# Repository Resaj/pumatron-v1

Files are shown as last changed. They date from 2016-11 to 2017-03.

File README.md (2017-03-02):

# Pumatrón V1
Pumatrón es mi primer robot de competición. Participó entre 2011 y 2013 en numerosas pruebas, como Alcabot, Cybertech, Robolid...

Se trata de un robot modular y autosoportado, capaz de adaptarse fácilmente a las pruebas de rastreadores, velocistas y laberinto.

<p align="center">
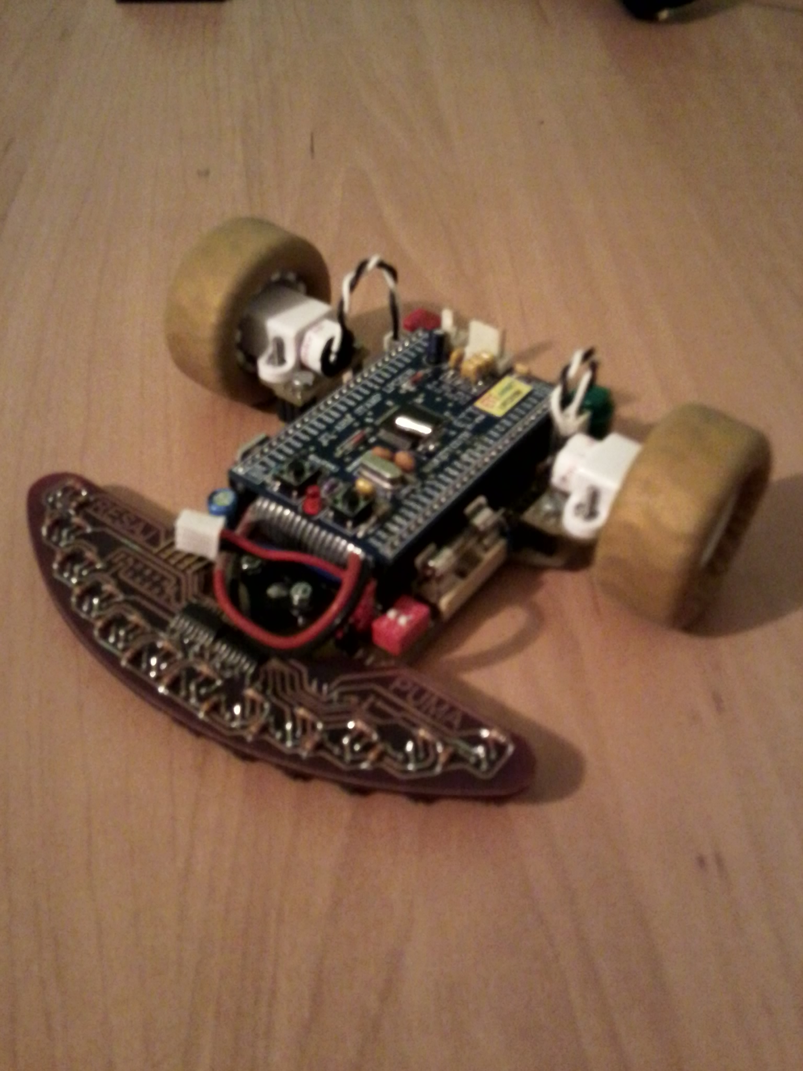
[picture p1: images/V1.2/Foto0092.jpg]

</p>

## Autor
[Rubén Espino San José](https://github.com/Resaj)

## License
<p align="center">

</p>

Todos estos productos están liberados mediante [Creative Commons Attribution-ShareAlike 4.0 International License](http://creativecommons.org/licenses/by-sa/4.0/).  
_All these products are released under [Creative Commons Attribution-ShareAlike 4.0 International License](http://creativecommons.org/licenses/by-sa/4.0/)._

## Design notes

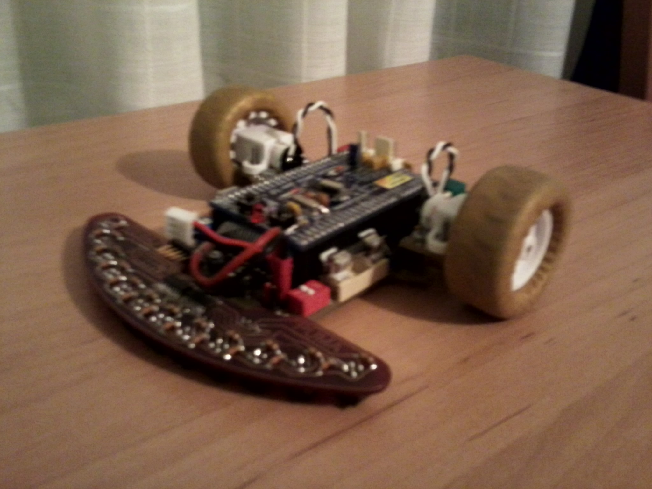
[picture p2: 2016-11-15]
images/V1.2/Foto0095.jpg

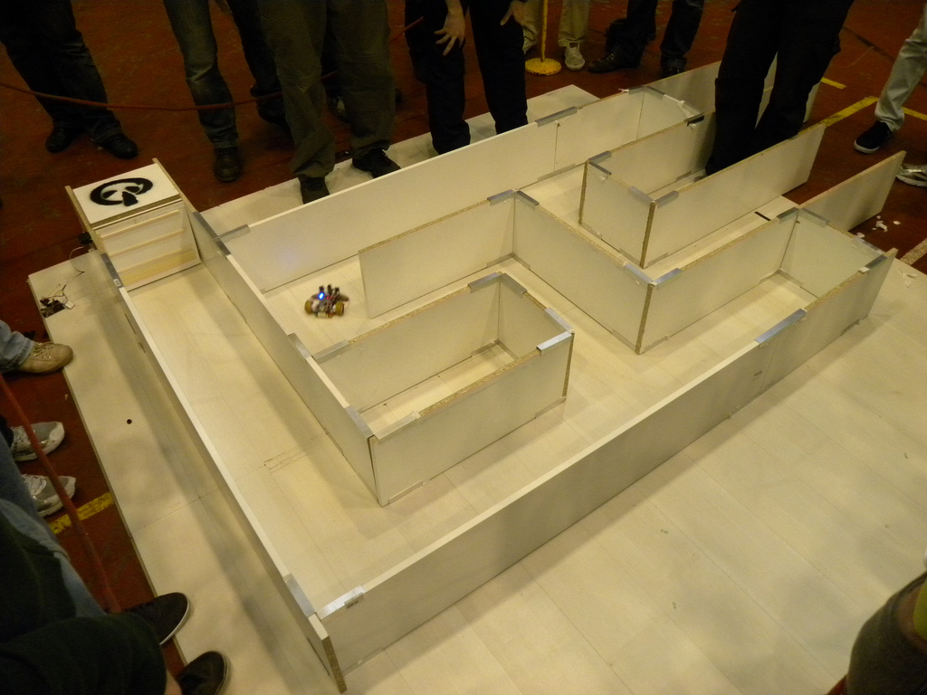
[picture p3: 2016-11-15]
images/V1.2/6978497396_52f8bebbc2_b.jpg

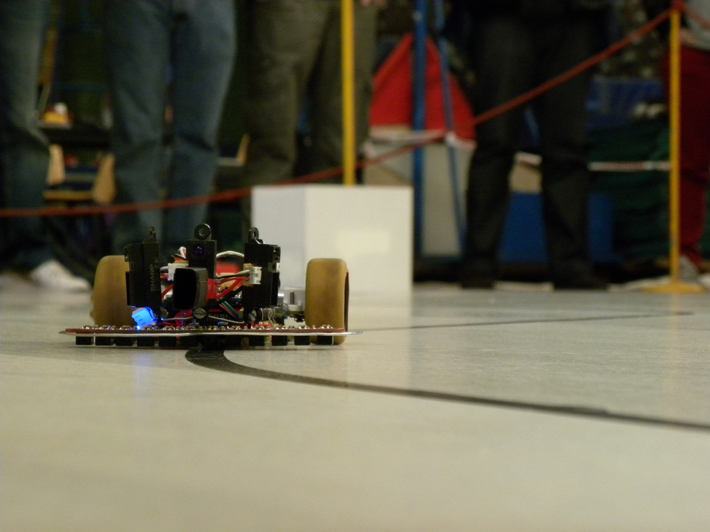
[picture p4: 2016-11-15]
images/V1.2/6978640872_f2e33e7ffb_b.jpg

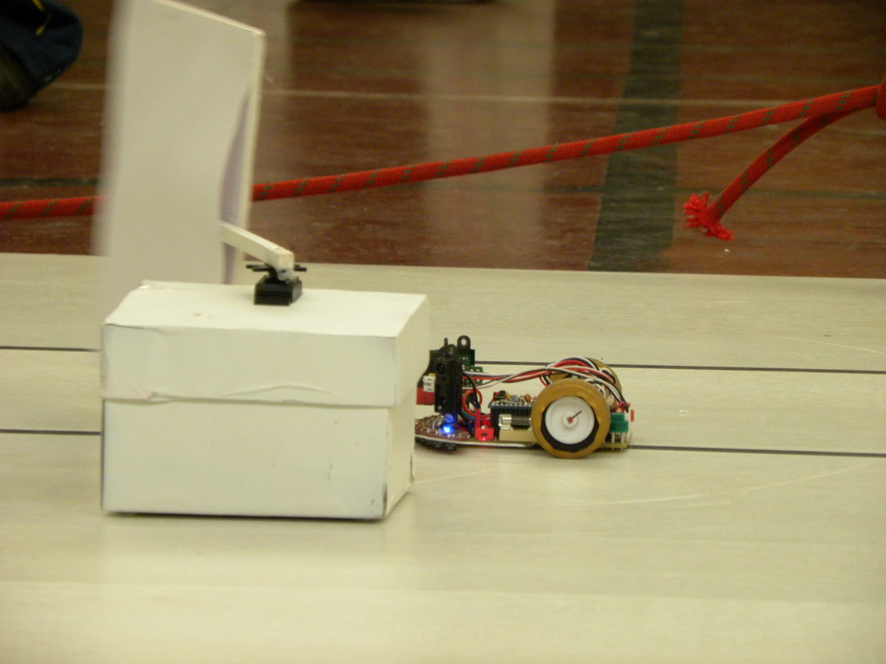
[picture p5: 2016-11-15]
images/V1.2/6978671704_61be949036_b.jpg

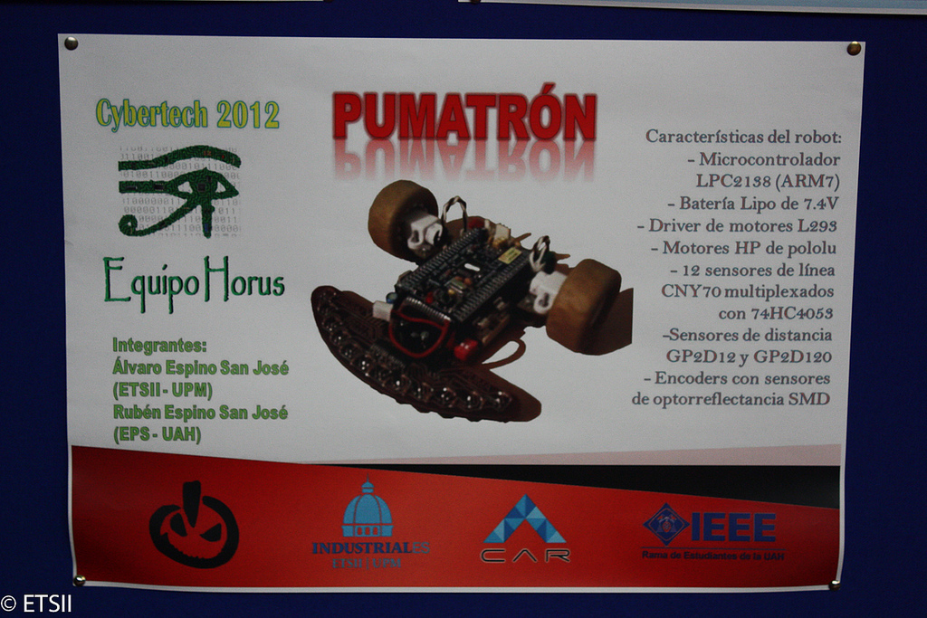
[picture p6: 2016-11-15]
images/V1.2/6982333434_18f1ba5d6d_b.jpg

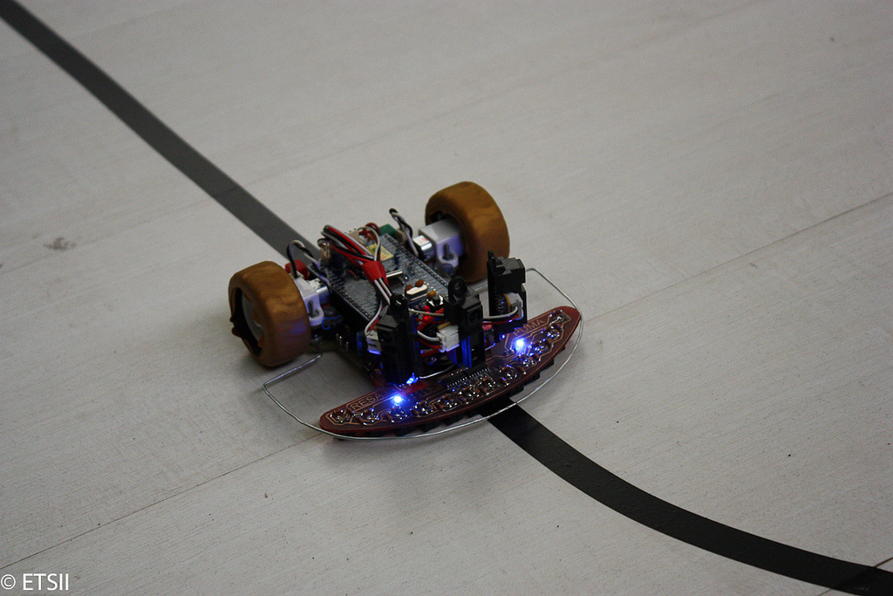
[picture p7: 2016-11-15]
images/V1.2/6982334384_aaf5ecdfa9_b.jpg

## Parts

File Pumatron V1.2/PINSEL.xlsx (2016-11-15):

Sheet: PINSEL
 | PINSEL0 | Pin Name | Function | Function | Function | Function | Reset |  | PINSEL2 | Pin Name | Function
 |  |  | when 00 | when 01 | when 10 | when 11 | Value |  |  |  | when 00
UART | 1 . 0 | P0.0 | GPIO Port 0.0 | TxD (UART0) | PWM1 | Reserved | 0 | LCD | 3 . 2 | P1.16 | GPIO Port 1.16
 | 3 . 2 | P0.1 | GPIO Port 0.1 | RxD (UART0) | PWM3 | EINT0 | 0 |  |  | P1.17 | GPIO Port 1.17
MEMORIA | 5 . 4 | P0.2 | GPIO Port 0.2 | SCL0 (I2C) | Capture 0.0 | Reserved | 0 |  |  | P1.18 | GPIO Port 1.18
PULSADOR / MEMORIA | 7 . 6 | P0.3 | GPIO Port 0.3 | SDA0 (I2C) | Match 0.0 | EINT1 | 0 |  |  | P1.19 | GPIO Port 1.19
SENSORES | 9 . 8 | P0.4 | GPIO Port 0.4 | SCK (SPI0) | Capture 0.1 | AD0.6 | 0 |  |  | P1.20 | GPIO Port 1.20
 | 11 . 10 | P0.5 | GPIO Port 0.5 | MISO (SPI0) | Match 0.1 | AD0.7 | 0 | INTERRUPTOR |  | P1.21 | GPIO Port 1.21
SENSORES DISTANCIA / WP MEMORIA | 13 . 12 | P0.6 | GPIO Port 0.6 | MOSI (SPI0) | Capture 0.2 | AD1.0 | 0 | LED |  | P1.22 | GPIO Port 1.22
PWM IZQUIERDO | 15 . 14 | P0.7 | GPIO Port 0.7 | SSEL (SPI0) | PWM2 | EINT2 | 0 | LED |  | P1.23 | GPIO Port 1.23
PWM DERECHO | 17 . 16 | P0.8 | GPIO Port 0.8 | TxD (UART1) | PWM4 | AD1.1 | 0 |  |  | P1.24 | GPIO Port 1.24
PULSADOR | 19 . 18 | P0.9 | GPIO Port 0.9 | RxD (UART1) | PWM6 | EINT3 | 0 |  |  | P1.25 | GPIO Port 1.25
ENCODER | 21 . 20 | P0.10 | GPIO Port 0.10 | RTS (UART1) | Capture 1.0 | AD1.2 | 0 |  |  | P1.26 | GPIO Port 1.26
 | 23 . 22 | P0.11 | GPIO Port 0.11 | CTS (UART1) | Capture 1.1 | SCL1 (I2C1) | 0 |  |  | P1.27 | GPIO Port 1.27
SENSORES DISTANCIA | 25 . 24 | P0.12 | GPIO Port 0.12 | DSR (UART1) | Match 1.0 | AD1.3 | 0 |  |  | P1.28 | GPIO Port 1.28
 | 27 . 26 | P0.13 | GPIO Port 0.13 | DTR (UART1) | Match 1.1 | AD1.4 | 0 |  |  | P1.29 | GPIO Port 1.29
PULSADOR LOAD | 29 . 28 | P0.14 | GPIO Port 0.14 | CD (UART1) | EINT1 | SDA1 (I2C1) | 0 | SENTIDO M.I. - |  | P1.30 | GPIO Port 1.30
SENSORES DISTANCIA | 31 . 30 | P0.15 | GPIO Port 0.15 | RI (UART1) | EINT2 | AD1.5 | 0 | SENTIDO M.I. + |  | P1.31 | GPIO Port 1.31
 | PINSEL1 | Pin Name | Function | Function | Function | Function | Reset
 |  |  | when 00 | when 01 | when 10 | when 11 | Value
TIMER | 1 . 0 | P0.16 | GPIO Port 0.16 | EINT0 | Match 0.2 | Capture 0.2 | 0
ENCODER | 3 . 2 | P0.17 | GPIO Port 0.17 | Capture 1.2 | SCK (SSP) | Match 1.2 | 0
SENSOR INFRARROJO | 5 . 4 | P0.18 | GPIO Port 0.18 | Capture 1.3 | MISO (SSP) | Match 1.3 | 0
 | 7 . 6 | P0.19 | GPIO Port 0.19 | Match 1.2 | MOSI (SSP) | Match 1.3 | 0
SENTIDO M.D. - | 9 . 8 | P0.20 | GPIO Port 0.20 | Match 1.3 | SSEL (SSP) | EINT3 | 0
PWM SERVO | 11 . 10 | P0.21 | GPIO Port 0.21 | PWM5 | AD1.6 | Capture 1.3 | 0
SENSORES DISTANCIA | 13 . 12 | P0.22 | GPIO Port 0.22 | AD1.7 | Capture 0.0 | Match 0.0 | 0
SENTIDO M.D. + | 15 . 14 | P0.23 | GPIO Port 0.23 | Reserved | Reserved | Reserved | 0
 | 17 . 16 | P0.24 | Reserved | Reserved | Reserved | Reserved | 0
MULTIPLEXOR | 19 . 18 | P0.25 | GPIO Port 0.25 | AD0.4 | Aout (DAC) | Reserved | 0
SENSORES | 21 . 20 | P0.26 | GPIO Port 0.26 | AD0.5 | Reserved | Reserved | 0
LED | 23 . 22 | P0.27 | GPIO Port 0.27 | AD0.0 | Capture 0.1 | Match 0.1 | 1
SENSORES | 25 . 24 | P0.28 | GPIO Port 0.28 | AD0.1 | Capture 0.2 | Match 0.2 | 1
 | 27 . 26 | P0.29 | GPIO Port 0.29 | AD0.2 | Capture 0.3 | Match 0.3 | 1
 | 29 . 28 | P0.30 | GPIO Port 0.30 | AD0.3 | EINT3 | Capture 0.0 | 1
LED | 31 . 30 | P0.31 | GPIO Port 0.31 | Reserved | Reserved | Reserved | 0

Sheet: Pines de la placa multiplexada
P0.27 |  | LED
P0.28 | AD0.1 | ZC_DER | sensor 6 | YC1_DER
 |  |  | sensor 7 | YC0_DER
P0.29 | AD0.2 | ZB_DER | sensor 8 | YB1_DER
 |  |  | sensor 9 | YB0_DER
P0.30 | AD0.3 | ZA_DER | sensor 10 | YA1_DER
 |  |  | sensor 11 | YA0_DER
P0.25 | AD0.4 | SELECT
P0.26 | AD0.5 | ZB_IZQ | sensor 4 | YB1_IZQ
 |  |  | sensor 5 | YB0_IZQ
P0.4 | AD0.6 | ZC_IZQ | sensor 2 | YC1_IZQ
 |  |  | sensor 3 | YC0_IZQ
P0.5 | AD0.7 | ZA_IZQ | sensor 0 | YA1_IZQ
 |  |  | sensor 1 | YA0_IZQ
P1.23 |  | LED

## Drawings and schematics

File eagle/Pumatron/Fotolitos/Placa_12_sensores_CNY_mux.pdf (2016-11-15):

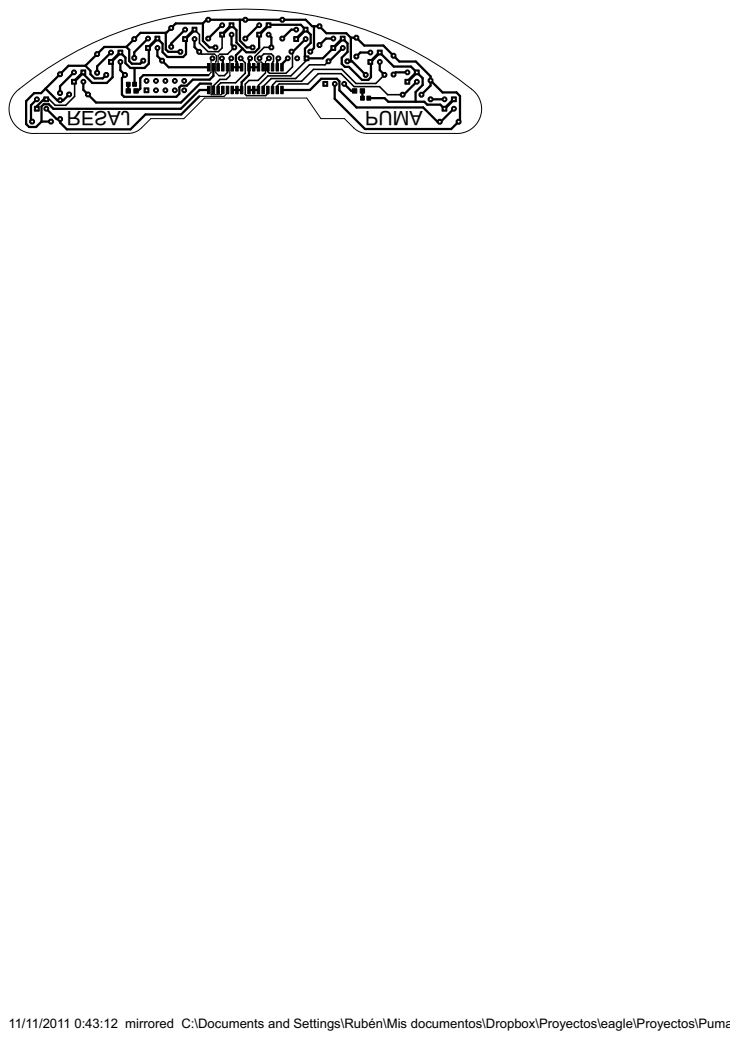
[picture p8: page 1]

11/11/2011 0:43:12 mirrored C:\Documents and Settings\Rubén\Mis documentos\Dropbox\Proyectos\eagle\Proyectos\Pumatrón\Placa_12_sensores_CNY_mux.brd

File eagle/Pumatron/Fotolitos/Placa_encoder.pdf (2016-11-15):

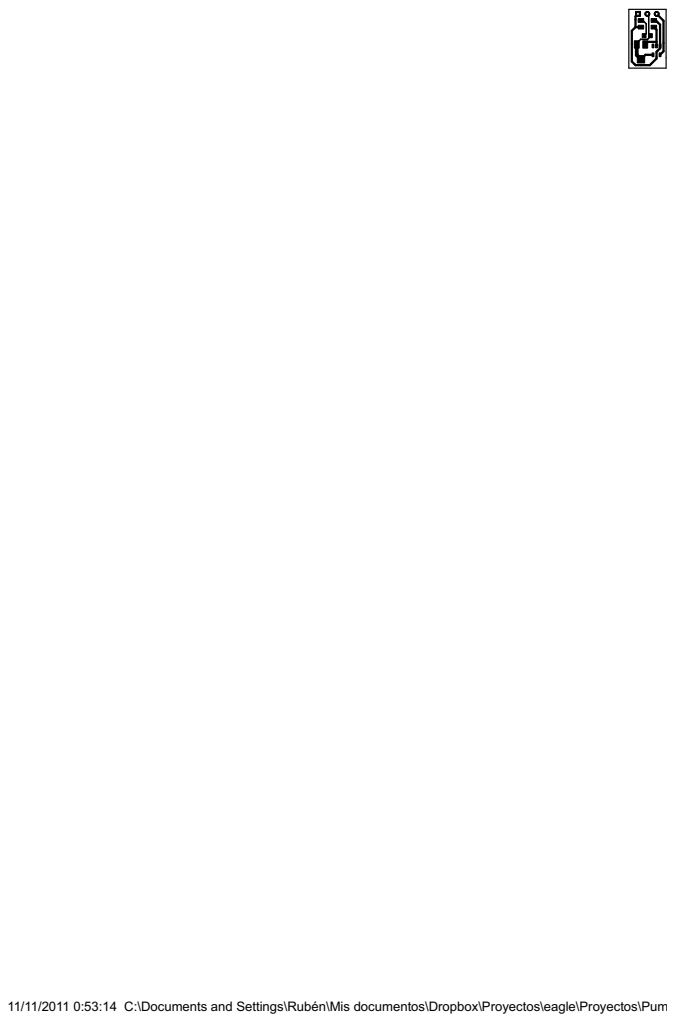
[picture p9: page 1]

11/11/2011 0:53:14 C:\Documents and Settings\Rubén\Mis documentos\Dropbox\Proyectos\eagle\Proyectos\Pum

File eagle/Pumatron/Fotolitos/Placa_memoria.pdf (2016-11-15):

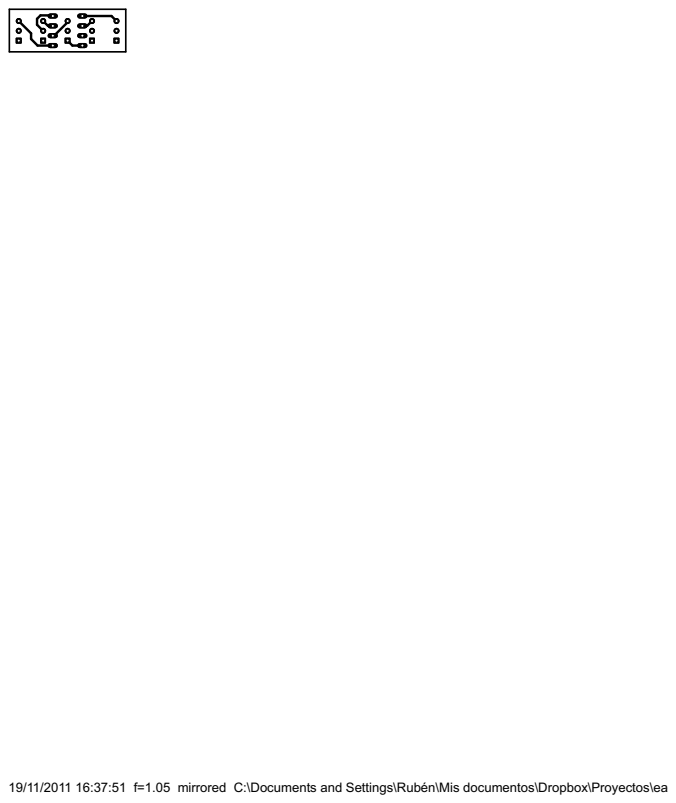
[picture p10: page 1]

19/11/2011 16:37:51 f=1.05 mirrored C:\Documents and Settings\Rubén\Mis documentos\Dropbox\Proyectos\ea

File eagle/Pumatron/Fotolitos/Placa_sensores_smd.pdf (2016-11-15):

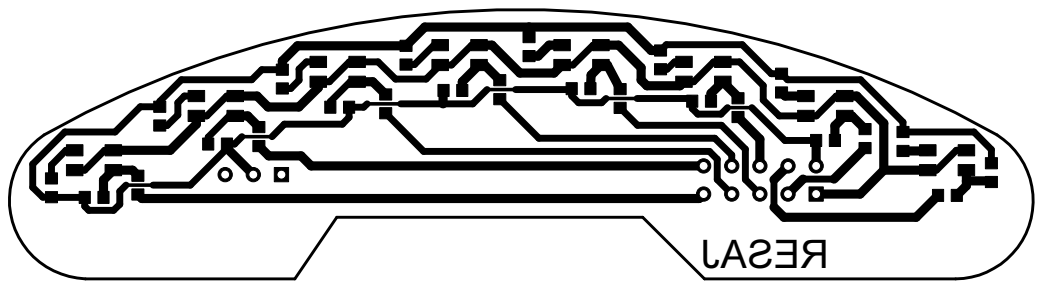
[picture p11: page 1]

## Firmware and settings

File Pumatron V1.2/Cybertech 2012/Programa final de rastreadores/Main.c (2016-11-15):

#include <lpc213x.h>
#include <stdbool.h>
#include "Declaraciones.h"
#include "PID.h"

/************************ VARIABLES ************************/
char ESTADO;

float Periodo = 5e-3;		// Periodo de ejecución del timer en modo match
float Per_pwm = 5e-4;		// Periodo de la PWM0

// Variables auxiliares 
char cadena[30];			// Variable auxiliar para guardar el texto a imprimir en el LCD
char start = '0';
unsigned int seg_espera = 0;
float cont = 0;
int i = 0, t = 0;
int flag = 1;

// Variables para el control del rastreo
unsigned int ADC0[8];			// Array para recoger los datos del ADC0
unsigned int ADC1_5;			// Variable para recoger los datos del ADC1
unsigned int ADCresult[S];		// Array con los datos del ADC ordenados
unsigned int LINEAresult[S];	// Array que contiene los valores digitalizados de ADCresult
unsigned int sensor_frontal = 0;
char mux = '0';					// Variable para conmutar el multiplexor
unsigned int inf = 0, sup = 0;			// Variables para la estimación de los umbrales

unsigned int umbral[S];			// Umbral para diferenciar 0 y 1 en la lectura del sensor
unsigned int blanco[S];	
unsigned int negro[S];

char LINEA = '0';
char giro = '0';				// Variable auxiliar para no perder la línea. Se inicia a un valor distinto a IZQ y DER
char GIRO = '0';				// Variable de orden de giro en cruces. Se inicia a un valor distinto a IZQ y DER
char GIRO_aux_izq = '0';
char GIRO_aux_der = '0';
char GIRO_aux = '0';
int aux_ant[3];					// Detecta la posición de la línea de giro respecto a la línea principal
int aux_act[4];
bool marca[7];
int negros = 0;					// Número de sensores en negro
char cond = '1';				// Condición para habilitar o deshabilitar la suma de la tercera línea

char secuencia_actual = '1';	// Secuencia de línea en el instante actual
char secuencia_anterior = '0';	// Secuencia de línea en el instante anterior
bool linea_buena = true;		// Línea buena tomada en el cruce

// Variables para el control de velocidad
float v_rapida = 1;				// Control de velocidad de rastreo normal. 1 max
float v_lenta = 0.4;			// Control de velocidad para las bifurcaciones. 1 max
float velocidad = 0.4;			// Velocidad de rastreo

//Variables PID
long sensors[S];
long sensors_average = 0;
int sensors_sum = 0;
int position = 0;
int proportional = 0;
long integral = 0;
long integral_max = 1000;
int derivative = 0;
int last_proportional = 0;
int control_value = 0;
int max_difference = 3000;	// 3000
float Kp = 2;		//4
float Ki = 0;		//0
float Kd = 50;		//50


/************************** FUNCIÓN MAIN **************************/
int main (void)
{
	ESTADO = Seleccion_velocidad;

	// Actualizar umbrales
	for(i=0; i<S; i++)
	{
		blanco[i] = 700;
		umbral[i] = 800;
		negro[i] = 900;
	}

	// Configuraciones previas
	//config_LCD();
	config_leds();
	config_EINT1();
	config_EINT3();
	config_MOTORES();
	config_ADC();
	//config_TIMER1();
	config_TIMER0();

	IO0PIN |= (1<<27)|(1<<31);
	IO1PIN &= ~(1<<22)|(1<<23);
	v_rapida = 1;

	start = '1';

	while(1) // Bucle infinito para la ejecución del programa
	{
	}
}

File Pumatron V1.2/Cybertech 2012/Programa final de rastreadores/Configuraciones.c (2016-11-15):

#include <lpc213x.h>
#include "Declaraciones.h"
#include "font.h"		
#include "s1d15g00.h"

/************************ CONFIGURACIONES ************************/
// Configuración de EINT1
void config_EINT1(void)
{
	PINSEL0 |= 1<<29;	//ó 3<<6
	EXTMODE |= 1<<1;
	EXTPOLAR |= 1<<1;
	VICVectAddr2 = (unsigned long) EXTERNA1;
	VICVectCntl2 = (0x20|15);
	VICIntEnable |= 1<<15;
}

// Configuración de EINT3
void config_EINT3(void)
{
	PINSEL0 |= 3<<18;
	EXTMODE |= 1<<3;
	EXTPOLAR &= ~(1<<3);
	VICVectAddr3 = (unsigned long) EXTERNA3;
	VICVectCntl3 = (0x20|17);
	VICIntEnable |= 1<<17;
}

// Configuración del ADC para los sensores
void config_ADC (void)
{
	PINSEL0 |= (1<<8)|(1<<9)|(1<<10)|(1<<11)|(3<<30);	// Habilitar ADC0[6,7] y ADC1[5]
	PINSEL1 |= (1<<20)|(1<<24)|(1<<26)|(1<<28);			// Habilitar ADC0[1,2,3,5]
	IO0DIR |= 1<<25; 									// Salida del multiplexor

	AD0CR = 0x200000;
	AD1CR = 0x200000;
}

// Configuración del Capture1.0 y Capture1.2
void config_TIMER1(void)
{
	PINSEL0 |= (1<<21);
	PINSEL1 |= (1<<2);
	T1TCR = 0x02;
	T1CTCR = 0;
	T1PR = 0;
	T1TCR = 0x01;
 	T1CCR = (3<<1)|(3<<7);
	VICVectCntl0 = (0x20|5);
	VICVectAddr0 = (unsigned long) TIMER1;
	VICIntEnable |= (1<<5);
}

// Configuración del Match0.2 del TIMER0
void config_TIMER0 (void)
{
	PINSEL1 |= 1<<1;
	T0TCR = 0x02;
	T0PR = 0;
	T0MCR = (1<<6)|(1<<7);
	T0MR2 = (unsigned long)(Periodo*Fpclk);
	VICVectAddr1 = (unsigned long) TIMER0;
	VICVectCntl1 = (0x20|4);
	T0TCR = 0x01;
	VICIntEnable |= 1<<4;
}

// Configuración de las salidas de PWM para los motores
void config_MOTORES (void)
{
	PINSEL0 |= (1<<15)|(1<<17);		// PWM2 y PWM4
	IO0DIR |= (1<<20)|(1<<23);		// Salidas para el sentido de los motores
	IO1DIR |= (1<<30)|(1<<31);
	PWMTCR = 0x02;					// Reset TIMER y PREESCALER										   
	PWMPR = 0;						// El PRESCALER no modifica la frecuencia
	PWMMR0 = Per_pwm * Fpclk;			// Periodo PWM									   
	PWMLER = (1<<0)|(1<<2)|(1<<4);	// Habilitar MATCH0, MATCH2 y MATCH4
	PWMMCR = 0x02;					// Reset TIMER COUNTER REGISTER ON MATCH0							   
	PWMPCR = (1<<10)|(1<<12);		// Habilitar PWM2 y PWM4 en flanco
	PWMTCR = (1<<0)|(1<<3);			// Habilitar PWM y comenzar la cuenta
}

// Configuración de los leds
void config_leds(void)
{
	IO0DIR |= (1<<31)|(1<<27);
	IO1DIR |= (1<<22)|(1<<23);
}

// Configuración del display
void config_LCD (void)
{
  LCD_BL_DIR();			// BL = Output
  LCD_CS_DIR();			// CS = Output
  LCD_SCLK_DIR();		// SCLK = Output
  LCD_SDATA_DIR();		// SDATA = Output
  LCD_RESET_DIR();		// RESET = Output
  LCD_SCLK_LOW();		// Standby SCLK
  LCD_CS_HIGH();		// Disable CS
  LCD_SDATA_HIGH();		// Standby SDATA
  LCD_BL_HIGH();		// Black Light ON = 100%

  InitLcd(); 			// Initial LCD
  LCDClearScreen();		// Limpiar pantalla
}

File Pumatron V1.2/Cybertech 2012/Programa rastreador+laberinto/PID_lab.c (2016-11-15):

#include <lpc213x.h>
#include <stdlib.h>
#include <stdio.h>
#include "Declaraciones.h"
#include "PID_lab.h"
#include "s1d15g00.h"

/********************** ALGORITMO PID **********************/
void get_PID_lab(void)
{
	if(PARED == IZQ)
		position_lab = sensor_izq;
	else // PARED == DER
		position_lab = sensor_der;

	proportional_lab = position_lab - 120;

	integral_lab = integral_lab + proportional_lab;
	if(abs(integral_lab) > integral_max_lab)
	{
		if(integral_lab > 0)
			integral_lab = integral_max_lab;
		else
			integral_lab = -integral_max_lab;
	}

	derivative_lab = proportional_lab - last_proportional_lab;
	last_proportional_lab = proportional_lab;

	control_value_lab = (float)(proportional_lab * Kp_lab + integral_lab * Ki_lab + derivative_lab * Kd_lab);

//	sprintf(cadena, "sensors_average_lab");   
//	LCDPutStr(cadena, 120, 10, SMALL, WHITE, BLACK);
//	sprintf(cadena, "%6d", sensors_average_lab);   
//	LCDPutStr(cadena, 105, 20, SMALL, WHITE, BLACK);
//	sprintf(cadena, "sensors_sum_lab");   
//	LCDPutStr(cadena, 90, 10, SMALL, WHITE, BLACK);
//	sprintf(cadena, "%6d", sensors_sum_lab);   
//	LCDPutStr(cadena, 75, 20, SMALL, WHITE, BLACK);
//	sprintf(cadena, "position_lab");   
//	LCDPutStr(cadena, 60, 10, SMALL, WHITE, BLACK);
//	sprintf(cadena, "%6d", position_lab);   
//	LCDPutStr(cadena, 45, 20, SMALL, WHITE, BLACK);
//	sprintf(cadena, "proportional_lab");
//	LCDPutStr(cadena, 30, 10, SMALL, WHITE, BLACK);
//	sprintf(cadena, "%6d", proportional_lab);   
//	LCDPutStr(cadena, 15, 20, SMALL, WHITE, BLACK);
}

void set_motors_lab(void)
{
	if(PARED == IZQ)
	{
		if(sensor_izq < 250 && sensor_frontal < 250 && sensor_der > 250)
		{
			IO1PIN &= ~(1<<30);
			IO1PIN |= 1<<31;
			IO0PIN |= (1<<20)|(1<<23);

			PWMMR2 = (float)velocidad_lab*Per_pwm*Fpclk;
			PWMMR4 = (float)velocidad_lab*Per_pwm*Fpclk;
		}
		else if(sensor_izq < 250 && sensor_frontal < 250)
		{
			IO1PIN &= ~(1<<30);
			IO1PIN |= 1<<31;
			IO0PIN &= ~(1<<23);
			IO0PIN |= 1<<20;

			PWMMR2 = (float)velocidad_lab/5*Per_pwm*Fpclk;
			PWMMR4 = (float)velocidad_lab/2*Per_pwm*Fpclk;
		}
		else
		{
			if(control_value_lab > max_difference_lab)
			{
				control_value_lab = max_difference_lab;

				cont += Periodo;

				if(cont < 0.2)
				{
					IO1PIN |= (1<<30)|(1<<31);
					IO0PIN &= ~(1<<20);
					IO0PIN |= 1<<23;
	
					PWMMR2 = (float)0.4*velocidad_lab*Per_pwm*Fpclk;
					PWMMR4 = (float)velocidad_lab*Per_pwm*Fpclk;
				}
				else
				{
					IO1PIN &= ~(1<<30);
					IO1PIN |= 1<<31;
					IO0PIN &= ~(1<<20);
					IO0PIN |= 1<<23;
	
					PWMMR2 = (float)velocidad_lab/5*Per_pwm*Fpclk;
					PWMMR4 = (float)velocidad_lab*Per_pwm*Fpclk;
				}
			}
			else
			{
				if(control_value_lab < -max_difference_lab)
					control_value_lab = -max_difference_lab;

				IO1PIN &= ~(1<<30);
				IO1PIN |= 1<<31;
				IO0PIN &= ~(1<<20);
				IO0PIN |= 1<<23;
		
				if(control_value_lab < 0)
				{
					PWMMR2 = (float)velocidad_lab*Per_pwm*Fpclk;
					PWMMR4 = (float)(max_difference_lab + control_value_lab)/max_difference_lab * velocidad_lab*Per_pwm*Fpclk;
				}
				else // if(control_value_lab >= 0)
				{
					PWMMR2 = (float)(max_difference_lab - control_value_lab)/max_difference_lab * velocidad_lab*Per_pwm*Fpclk;
					PWMMR4 = (float)velocidad_lab*Per_pwm*Fpclk;
				}

				cont = 0;
			}
		}
	}
	else // PARED == DER
	{
		if(sensor_der < 250 && sensor_frontal < 250 && sensor_izq > 250)
		{
			IO1PIN |= (1<<30)|(1<<31);
			IO0PIN &= ~(1<<20);
			IO0PIN |= 1<<23;

			PWMMR2 = (float)velocidad_lab*Per_pwm*Fpclk;
			PWMMR4 = (float)velocidad_lab*Per_pwm*Fpclk;
		}
		else if(sensor_der < 250 && sensor_frontal < 250)
		{
			IO1PIN |= 1<<30;
			IO1PIN &= ~(1<<31);
			IO0PIN &= ~(1<<20);
			IO0PIN |= 1<<23;

			PWMMR2 = (float)velocidad_lab/2*Per_pwm*Fpclk;
			PWMMR4 = (float)velocidad_lab/5*Per_pwm*Fpclk;
		}
		else
		{
			if(control_value_lab > max_difference_lab)
			{
				control_value_lab = max_difference_lab;

				cont += Periodo;

				if(cont < 0.2)
				{
					IO1PIN &= ~(1<<30);
					IO1PIN |= (1<<31);
					IO0PIN |= (1<<20)|(1<<23);
	
					PWMMR2 = (float)velocidad_lab*Per_pwm*Fpclk;
					PWMMR4 = (float)0.4*velocidad_lab*Per_pwm*Fpclk;
				}
				else
				{
					IO1PIN &= ~(1<<30);
					IO1PIN |= 1<<31;
					IO0PIN &= ~(1<<20);
					IO0PIN |= 1<<23;
	
					PWMMR2 = (float)velocidad_lab*Per_pwm*Fpclk;
					PWMMR4 = (float)velocidad_lab/5*Per_pwm*Fpclk;
				}
			}
			else
			{
				if(control_value_lab < -max_difference_lab)
					control_value_lab = -max_difference_lab;

				IO1PIN &= ~(1<<30);
				IO1PIN |= 1<<31;
				IO0PIN &= ~(1<<20);
				IO0PIN |= 1<<23;
		
				if(control_value_lab < 0)
				{
					PWMMR2 = (float)(max_difference_lab - control_value_lab)/max_difference_lab * velocidad_lab*Per_pwm*Fpclk;
					PWMMR4 = (float)velocidad_lab*Per_pwm*Fpclk;
				}
				else // if(control_value_lab >= 0)
				{
					PWMMR2 = (float)velocidad_lab*Per_pwm*Fpclk;
					PWMMR4 = (float)(max_difference_lab + control_value_lab)/max_difference_lab * velocidad_lab*Per_pwm*Fpclk;
				}

				cont = 0;
			}
		}
	}

	PWMLER = (1<<0)|(1<<2)|(1<<4);
}

void loop_PID_lab(void)
{
	get_PID_lab();
	set_motors_lab();
}

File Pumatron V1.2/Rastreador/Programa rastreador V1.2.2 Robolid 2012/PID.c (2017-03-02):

#include <lpc213x.h>
#include <stdlib.h>
#include <stdio.h>
#include "Declaraciones.h"
#include "PID.h"
#include "s1d15g00.h"

/********************** ALGORITMO PID **********************/
void get_PID(void)
{
	sensors_average = 0;
	sensors_sum = 0;
	for(i = 0; i < S; i++)		   
	{
		sensors[i] = (ADCresult[i]-blanco[i])*1000/(negro[i]-blanco[i]);

		if(((ESTADO == Rastrear || ESTADO == Bifurcacion_proxima) && sensors[i] < 100) || 
			((LINEAresult[i] == 1 && sensors[i] < 200) || LINEAresult[i] == 0))
				sensors[i] = 0;

		sensors_average += sensors[i]*(i+1)*1000;
		sensors_sum += sensors[i];
	}

	if(negros == 0)
	{
		if(giro == IZQ)
			position = (S+1)*1000;
		else // giro == DER
			position = 0;
	}
	else // sensors_sum != 0
		position = sensors_average / sensors_sum;

	proportional = position - (S+1)*1000/2;

	if(negros != 0)
	{
		if(proportional < -3500)
			giro = DER;
		else if(proportional > 3500)
			giro = IZQ;
	}

	integral = integral + proportional;
	if(abs(integral) > integral_max)
	{
		if(integral > 0)
			integral = integral_max;
		else
			integral = -integral_max;
	}

	derivative = proportional - last_proportional;
	last_proportional = proportional;

	control_value = (float)(proportional * Kp + integral * Ki + derivative * Kd);

//	for(i = 0; i < S; i++)
//	{
//		if(ADCresult[i] > umbral[i])
//			LCDSetRect((120-(i*10)), 5, (125-(i*10)), 10, 1, RED);
//		else
//			LCDSetRect((120-(i*10)), 5, (125-(i*10)), 10, 1, WHITE);
//
//		sprintf(cadena, "%4d", ADCresult[i]);
//		LCDPutStr(cadena, (120-(i*10)), 15, SMALL, WHITE, BLACK);
//	}
//	sprintf(cadena, "sensors_average");   
//	LCDPutStr(cadena, 120, 60, SMALL, WHITE, BLACK);
//	sprintf(cadena, "%6d", sensors_average);   
//	LCDPutStr(cadena, 105, 70, SMALL, WHITE, BLACK);
//	sprintf(cadena, "sensors_sum");   
//	LCDPutStr(cadena, 90, 60, SMALL, WHITE, BLACK);
//	sprintf(cadena, "%6d", sensors_sum);   
//	LCDPutStr(cadena, 75, 70, SMALL, WHITE, BLACK);
//	sprintf(cadena, "position");   
//	LCDPutStr(cadena, 60, 60, SMALL, WHITE, BLACK);
//	sprintf(cadena, "%6d", position);   
//	LCDPutStr(cadena, 45, 70, SMALL, WHITE, BLACK);
//	sprintf(cadena, "proportional");
//	LCDPutStr(cadena, 30, 60, SMALL, WHITE, BLACK);
//	sprintf(cadena, "%6d", proportional);   
//	LCDPutStr(cadena, 15, 70, SMALL, WHITE, BLACK);
}

void set_motors(void)
{
	if(velocidad < v_rapida && ESTADO != Bifurcacion_proxima && ESTADO != Bifurcacion)
	{
		velocidad += 0.02;
		if(velocidad > v_rapida)
			velocidad = v_rapida;
	}

//	if(abs(control_value) < max_difference/2)
//	{
//		IO1PIN &= ~(1<<30);
//		IO1PIN |= 1<<31;
//		IO0PIN &= ~(1<<20);
//		IO0PIN |= 1<<23;
//
//		if(control_value < 0)
//		{
//			PWMMR2 = (float)velocidad*Per_pwm*Fpclk;
//			PWMMR4 = (float)(max_difference/2 + control_value)/max_difference/2 * velocidad*Per_pwm*Fpclk;
//		}
//		else
//		{
//			PWMMR2 = (float)(max_difference/2 - control_value)/max_difference/2 * velocidad*Per_pwm*Fpclk;
//			PWMMR4 = (float)velocidad*Per_pwm*Fpclk;
//		}
//	}
//	else
//	{
//		if(control_value > max_difference)
//			control_value = max_difference;
//		else if(control_value < -max_difference)
//			control_value = -max_difference;
//
//		if(control_value < 0)
//		{
//			IO1PIN &= ~(1<<30);
//			IO1PIN |= 1<<31;
//			IO0PIN &= ~(1<<23);
//			IO0PIN |= 1<<20;
//
//			PWMMR2 = (float)velocidad*Per_pwm*Fpclk;
//			PWMMR4 = (float)(-max_difference/2 - control_value)/max_difference/2 * velocidad*Per_pwm*Fpclk;
//		}
//		else
//		{
//			IO1PIN &= ~(1<<31);
//			IO1PIN |= 1<<30;
//			IO0PIN &= ~(1<<20);
//			IO0PIN |= 1<<23;
//
//			PWMMR2 = (float)(-max_difference/2 + control_value)/max_difference/2 * velocidad*Per_pwm*Fpclk;
//			PWMMR4 = (float)velocidad*Per_pwm*Fpclk;
//		}
//	}

	if(negros == 0)
	{
		if(giro == IZQ)
		{
			IO0PIN &= ~(1<<20);
			IO0PIN |= 1<<23;
			IO1PIN |= 1<<30;
			IO1PIN &= ~(1<<31);
			PWMMR2 = (float)velocidad*Per_pwm*Fpclk;
			PWMMR4 = (float)velocidad*Per_pwm*Fpclk/2;
		}
		else if(giro == DER)
		{
			IO0PIN &= ~(1<<23);
			IO0PIN |= 1<<20;
			IO1PIN &= ~(1<<30);
			IO1PIN |= 1<<31;
			PWMMR2 = (float)velocidad*Per_pwm*Fpclk/2;
			PWMMR4 = (float)velocidad*Per_pwm*Fpclk;
		}
	}
	else
	{
		if(control_value > max_difference)
		{
			control_value = max_difference;
			IO1PIN |= (1<<30)|(1<<31);
			IO0PIN &= ~(1<<20);
			IO0PIN |= 1<<23;

			PWMMR2 = (float)Per_pwm*Fpclk;
			PWMMR4 = (float)velocidad*Per_pwm*Fpclk;
		}
		else if(control_value < -max_difference)
		{
			control_value = -max_difference;
			IO1PIN &= ~(1<<30);
			IO1PIN |= 1<<31;
			IO0PIN |= (1<<20)|(1<<23);

			PWMMR2 = (float)velocidad*Per_pwm*Fpclk;
			PWMMR4 = (float)Per_pwm*Fpclk;
		}
		else
		{
//			if(control_value > max_difference)
//				control_value = max_difference;
//			else if(control_value < -max_difference)
//				control_value = -max_difference;

			IO1PIN &= ~(1<<30);
			IO1PIN |= 1<<31;
			IO0PIN &= ~(1<<20);
			IO0PIN |= 1<<23;
	
			if(control_value < 0)
			{
				PWMMR2 = (float)velocidad*Per_pwm*Fpclk;
				PWMMR4 = (float)(max_difference + control_value)/max_difference * velocidad*Per_pwm*Fpclk;
			}
			else //if(control_value >= 0)
			{
				PWMMR2 = (float)(max_difference - control_value)/max_difference * velocidad*Per_pwm*Fpclk;
				PWMMR4 = (float)velocidad*Per_pwm*Fpclk;
			}
		}
	}

	PWMLER = (1<<0)|(1<<2)|(1<<4);
}

void loop_PID(void)
{
	get_PID();
	set_motors();
}
